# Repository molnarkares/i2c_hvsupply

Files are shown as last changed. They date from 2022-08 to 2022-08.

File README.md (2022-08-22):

# I2C controlled High voltage power supply for GM tubes

The device implements an I2C controlled variable output power supply (400V-600V), 
a GM tube pulse counter and an optional wake-up timer to trigger the host processor periodically.

The device was designed to keep the power consumption as low as possible. 

## Hardware

The physical hardware is a non-isolated flyback controller with 
voltage multiplier. The output voltage can be controlled by injecting bias current in the feedback loop of the controller IC. The circuit is using a PIC16LF1764 microcontroller.

## Firmware

The firmware is implemented in C using the Free License variant of the 
Microchip XC8 compiler 
See the readme in the firmware folder for details on operation and rebuild.

## Documentation

A comprehensive Users Manual is available in Latex format and converted to PDF in the doc folder.

## License

The project is available under MIT license, see the details in the sub-folders.

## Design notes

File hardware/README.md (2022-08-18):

# I2C controlled High voltage power supply for GM tubes

The device implements an I2C controlled variable output power supply (400V-600V), 
a GM tube pulse counter and an optional wake-up timer to trigger the host processor periodically.

The device was designed to keep the power consumption as low as possible. 

See the detailed Users Manual in the doc folder one level up. 

# PCB and Schematic Design

The circuit schematic and PCB was designed by [DesignSpark PCB v10](https://www.rs-online.com/designspark/pcb-software).

# License

## Hardware was designed by the Author

The complete desiggn is available under MIT license.

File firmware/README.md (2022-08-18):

# I2C controlled High voltage power supply for GM tubes

The device implements an I2C controlled variable output power supply (400V-600V), 
a GM tube pulse counter and an optional wake-up timer to trigger the host processor periodically.

The device was designed to keep the power consumption as low as possible. 

See the detailed Users Manual in the doc folder one level up. 

# Building the application

The BL can be built with the free version of the Microchip XC8 compiler. 
The related Makefile is exported from the MPLAB IDE. 
The software can be compiled with executing the _make_ command.

There are two build targets: 
* the _default_ target will link the application from the start address 0, 
so it can be uploaded by a debugger.
* the _reloc_ target will link to 0x400 and it is meant for uploading via the 
[I2C Boot loader](https://github.com/molnarkares/pic16f_i2cbl).

Observe that the software was developed on Linux host. a number of path settings
in the Makefile might require adjustment to rebuild it on other host OSes.

# License

## Code written by the Author

The complete business logic is written by the Author and it is available under MIT license.

## Generated code

The low level device drivers are generated by the Microchip MPLAB Code Configurator.
The generated code has its own copyright in the header of the concerned files.
These include the following files:
_tmr1-2-3-5.c/h_, _pin_manager.c/h_, _memory.c/h_, _mcc.c/h_, _i2c.c/h_, clc1-2.c/h and _interrupt_manager.h_

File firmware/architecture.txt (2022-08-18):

@startuml
package "Pulse counter" as pulsecounter {
    component TMR3_16 #Green
    component TMR2_8 #Green
    component CLC2 #Yellow

    TMR3_16 -> CLC2
    CLC2 -> TMR2_8
}
package "Periodic notification timer" as sectimer {
    component TMR1_16 #Green
    component TMR5_16 #Green
    component CLC1 #Yellow
    
    TMR1_16 -> CLC1
    CLC1 -> PA2
    PA2 -> TMR5_16

}
package pwm {
    component PWM5 #Green
}
package "Command processor" as cmd {
    
    database registermap
    node commander
    component i2c #Green    
}
package System {
    component LFINTOSC #Green
}

interface "PWM output" as RC4
interface "TRIG" as RC2
interface "Pulse IN" as RC5 
interface "Secondary OSC" as RA4_5

interface "SCL" as RA1
interface "SDA" as RA0

TMR1_16 <-- RA4_5
TMR3_16 <-- RC5

RA1 <-up-> i2c
RA0 <-up-> i2c

PWM5 -down-> RC4
registermap <-> commander
i2c <-left-> commander
commander -down-> RC2
commander -> pwm

note bottom of TMR5_16
wakes up MCU after a given number of seconds
end note 
note bottom of i2c
wakes up MCU at address match
end note 

LFINTOSC -> commander
LFINTOSC -> PWM5
LFINTOSC -> i2c
@enduml

@startuml
start
if (Connection to Ginkgo sucessful?) then (yes)
#Cyan: Verify primary I2C connection
    by reading the default I2C values;
    if (Values matching default) then(yes)
#Cyan: Test pulse counter;
        if (pulse readback matches) then(yes)
        #Cyan: Test timeout and TRIG pin;
            if (Timout within 1ms jitter?) then (yes)
            #Cyan: Calibrate ADC;
            #Cyan: Write back VADJUST values;
            #Cyan: Write serial number;
            #Cyan: Write default values
            Vout disabled
            No timeout;
            else (no)
            #Crimson:report Error;
            stop
        endif
        else(no)
#Crimson:report Error;
        stop
        endif
    else(no)
#Crimson: report Error;
    stop
    endif
else (no)
#Crimson:report Error;
  stop
endif
end

@enduml

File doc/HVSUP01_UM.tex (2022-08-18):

% This file was converted to LaTeX by Writer2LaTeX ver. 1.4
% see http://writer2latex.sourceforge.net for more info
\documentclass[a4paper]{article}
\usepackage[ascii]{inputenc}
\usepackage[T1]{fontenc}
\usepackage[english]{babel}
\usepackage{amsmath}
\usepackage{amssymb,amsfonts,textcomp}
\usepackage{color}
\usepackage{array}
\usepackage{supertabular}
\usepackage{hhline}
\usepackage{hyperref}
\hypersetup{pdftex, colorlinks=true, linkcolor=blue, citecolor=blue, filecolor=blue, urlcolor=blue, pdftitle=, pdfauthor=, pdfsubject=, pdfkeywords=}
\usepackage[pdftex]{graphicx}
% footnotes configuration
\makeatletter
\renewcommand\thefootnote{\arabic{footnote}}
\makeatother
% Outline numbering
\setcounter{secnumdepth}{0}
\makeatletter
\newcommand\arraybslash{\let\\\@arraycr}
\makeatother
% List styles
\newcommand\liststyleLi{%
\renewcommand\labelitemi{{\textbullet}}
\renewcommand\labelitemii{${\circ}$}
\renewcommand\labelitemiii{${\blacksquare}$}
\renewcommand\labelitemiv{{\textbullet}}
}
\newcommand\liststyleLii{%
\renewcommand\theenumi{\arabic{enumi}}
\renewcommand\theenumii{\arabic{enumii}}
\renewcommand\theenumiii{\arabic{enumiii}}
\renewcommand\theenumiv{\arabic{enumiv}}
\renewcommand\labelenumi{\theenumi.}
\renewcommand\labelenumii{\theenumii.}
\renewcommand\labelenumiii{\theenumiii.}
\renewcommand\labelenumiv{\theenumiv.}
}
% Page layout (geometry)
\setlength\voffset{-1in}
\setlength\hoffset{-1in}
\setlength\topmargin{0.7874in}
\setlength\oddsidemargin{0.7874in}
\setlength\textheight{9.235in}
\setlength\textwidth{6.695299in}
\setlength\footskip{0.4402in}
\setlength\headheight{0.2402in}
\setlength\headsep{0.2in}
% Footnote rule
\setlength{\skip\footins}{1.18034mm}
\renewcommand\footnoterule{\vspace*{-0.0071in}\setlength\leftskip{0pt}\setlength\rightskip{0pt plus 1fil}\noindent\textcolor{black}{\rule{0.25\columnwidth}{0.0071in}}\vspace*{1mm}}
% Pages styles
\makeatletter
\newcommand\ps@Standard{
  \renewcommand\@oddhead{}
  \renewcommand\@evenhead{\@oddhead}
  \renewcommand\@oddfoot{August 2022 \hfill {\textcopyright} Karoly Molnar \hfill Specification subject to change without notice. }
  \renewcommand\@evenfoot{\@oddfoot}
  \renewcommand\thepage{\arabic{page}}
}
\makeatother
\pagestyle{Standard}
\setlength\tabcolsep{1mm}
\renewcommand\arraystretch{1.3}
\newcounter{Drawing}
\renewcommand\theDrawing{\arabic{Drawing}}
\title{}
\author{}
\date{2020-10-24}
\begin{document}

\bigskip

{\centering\selectlanguage{english}\sffamily\bfseries
HVSUP01
\par}

{\centering\selectlanguage{english}\sffamily
Composite I2C sensor 
\par}

{\centering\selectlanguage{english}\sffamily
for 
\par}

{\centering\selectlanguage{english}\sffamily
radiation detector (GM) tubes
\par}

\bigskip

\bigskip

\bigskip

{\centering\selectlanguage{english}\sffamily
User Manual
\par}

\setcounter{tocdepth}{10}
\renewcommand\contentsname{Table of Contents}
\tableofcontents
\section[]{\selectlanguage{english} }
\clearpage\section[Introduction]{\selectlanguage{english} Introduction}
\hypertarget{RefHeadingToc1311383566216}{}{\selectlanguage{english}
The HVSUP01 sensor provides simple and flexible interface between a host processor and a radiation detector tube. The
device requires minimal external components and its properties can be configured via I2C interface. The low current
consumption of the sensor makes it ideal for building ultra low power radiation detector devices.}

\section[HIGH VOLTAGE WARNING]{\selectlanguage{english} HIGH VOLTAGE WARNING}
\hypertarget{RefHeadingToc3481383566216}{}\begin{center}
\tablefirsthead{}
\tablehead{}
\tabletail{}
\tablelasttail{}
\begin{supertabular}{|m{6.6163597in}|}
\hline
{\selectlanguage{english}\color[rgb]{0.8,0.0,0.0} The sensor is producing high voltage during normal operation. }

{\selectlanguage{english}\color[rgb]{0.8,0.0,0.0} Its pins, including any electrically conductive device that is
connected to its terminals, must not be touched while the device is operational. }

{\selectlanguage{english}\color[rgb]{0.8,0.0,0.0} The high voltage terminals shall be shorted after powering off the
device, to make sure that no high voltage charge remains in the sensor.}\\\hline
\end{supertabular}
\end{center}
\section[]{\selectlanguage{english} }
\section[Features]{\selectlanguage{english} Features}
\hypertarget{RefHeadingToc2781383566216}{}\liststyleLi
\begin{itemize}
\item {\selectlanguage{english}
3V input}
\item {\selectlanguage{english}
400-600V output voltage, digitally adjustable}
\item {\selectlanguage{english}
low input current typ. {\textless}60uA at 400V output and no load}
\item {\selectlanguage{english}
24 bits pulse counter}
\item {\selectlanguage{english}
Timer with crystal oscillator to trigger Wake{}-up output}
\item {\selectlanguage{english}
Built-in output current limiting resistor 4.5MOhm}
\item {\selectlanguage{english}
I2C slave interface max 400kHz}
\item {\selectlanguage{english}
I2C address is 0x6E (7bits)}
\end{itemize}
\section[]{\selectlanguage{english} }
\clearpage\section[Technical specifications]{\selectlanguage{english} Technical specifications}
\hypertarget{RefHeadingToc1331383566216}{}\subsection[Electrical parameters]{\selectlanguage{english} Electrical
parameters}
\hypertarget{RefHeadingToc2801383566216}{}\begin{center}
\tablefirsthead{}
\tablehead{}
\tabletail{}
\tablelasttail{}
\begin{supertabular}{|m{4.21016in}|m{2.32756in}|}
\hline
{\selectlanguage{english}\bfseries Absolute ratings} &
{\selectlanguage{english}\bfseries Value}\\\hline
{\selectlanguage{english} Supply voltage Vcc} &
{\selectlanguage{english} 2.6V -- 3.5V}\\\hline
{\selectlanguage{english} Output Voltage} &
{\selectlanguage{english} 400V-600V digitally adjustable}\\\hline
{\selectlanguage{english} Output resistance} &
{\selectlanguage{english} 4.5MOhm}\\\hline
{\selectlanguage{english} Maximum voltage on digital I/O pins} &
{\selectlanguage{english} Supply voltage + 0.2V}\\\hline
\end{supertabular}
\end{center}

\bigskip

\begin{center}
\tablefirsthead{}
\tablehead{}
\tabletail{}
\tablelasttail{}
\begin{supertabular}{|m{4.21016in}|m{2.32756in}|}
\hline
\multicolumn{2}{|m{6.61646in}|}{{\selectlanguage{english}\bfseries Typical parameters @ 3V input voltage}}\\\hline
{\selectlanguage{english} Output Voltage accuracy @no load} &
{\selectlanguage{english} +/-3V}\\\hline
{\selectlanguage{english} Standby current consumption with output disabled} &
{\selectlanguage{english} 5uA}\\\hline
{\selectlanguage{english} Standby current consumption @400V no load} &
{\selectlanguage{english} 60uA}\\\hline
{\selectlanguage{english} Standby current consumption @500V no load} &
{\selectlanguage{english} 90uA}\\\hline
{\selectlanguage{english} Standby current consumption @600V no load} &
{\selectlanguage{english} 120uA}\\\hline
{\selectlanguage{english} Inrush current at starting the high voltage stage } &
{\selectlanguage{english} 300mA @ 40ms}\\\hline
\end{supertabular}
\end{center}
\clearpage\subsection[Timing parameters]{\selectlanguage{english} Timing parameters}
\hypertarget{RefHeadingToc7013613373551}{}\label{bkm:RefHeadingToc7013613373551}\begin{center}
\tablefirsthead{}
\tablehead{}
\tabletail{}
\tablelasttail{}
\begin{supertabular}{|m{4.20946in}|m{2.3281598in}|}
\hline
\multicolumn{2}{|m{6.6163597in}|}{{\selectlanguage{english}\bfseries Typical parameters at 3V input voltage}}\\\hline
{\selectlanguage{english} Pulse width of TRIG output} &
{\selectlanguage{english} approx. 1 msec}\\\hline
{\selectlanguage{english} Wake-up timeout accuracy} &
{\selectlanguage{english} +/- 30ppm}\\\hline
{\selectlanguage{english} I2C interface clock frequency} &
{\selectlanguage{english} max 400kHz}\\\hline
{\selectlanguage{english} Detected pulses per second} &
{\selectlanguage{english} 0...5000}\\\hline
{\selectlanguage{english} I2C clock stretching } &
{\selectlanguage{english} max 10ms}\\\hline
{\selectlanguage{english} Voltage ramp-up time} &
{\selectlanguage{english} approx. 50 sec}\\\hline
\end{supertabular}
\end{center}
\subsection[Environmental conditions]{\selectlanguage{english} Environmental conditions}
\hypertarget{RefHeadingToc2821383566216}{}\begin{center}
\tablefirsthead{}
\tablehead{}
\tabletail{}
\tablelasttail{}
\begin{supertabular}{|m{4.21016in}|m{2.32756in}|}
\hline
\multicolumn{2}{|m{6.61646in}|}{{\selectlanguage{english}\bfseries Absolute ratings}}\\\hline
{\selectlanguage{english} Operational temperature} &
{\selectlanguage{english} {}-20{\textdegree}C ... 50{\textdegree}C}\\\hline
{\selectlanguage{english} Storage temperature} &
{\selectlanguage{english} {}-20{\textdegree}C ... 70{\textdegree}C}\\\hline
{\selectlanguage{english} Relative Humidity} &
{\selectlanguage{english} 10\%..90\% non-condensing}\\\hline
\end{supertabular}
\end{center}
\clearpage\section[Operation]{\selectlanguage{english} Operation}
\hypertarget{RefHeadingToc1351383566216}{}\subsection[General behavior]{\selectlanguage{english} General behavior}
\hypertarget{RefHeadingToc2841383566216}{}{\selectlanguage{english}
The device is an I2C slave peripheral that can output high voltage. It is intended to count the detected pulses of a
connected GM tube. The sensor contains all signal shaping circuit that is necessary for accurate and error-free
detection of the pulses.}

\bigskip

\subsection[]{\selectlanguage{english} }
\begin{center}
\begin{minipage}{3.2874in}
{\selectlanguage{english}\itshape
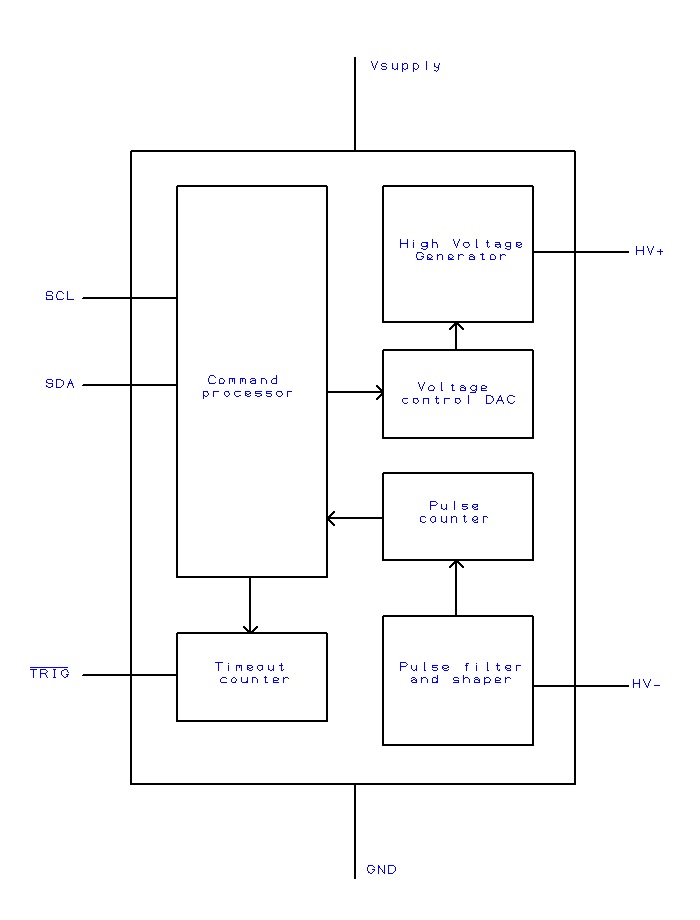
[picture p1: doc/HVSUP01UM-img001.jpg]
  \stepcounter{Drawing}{\theDrawing}. Drawing:
Block diagram}
\end{minipage}
\end{center}
\subsection[]{\selectlanguage{english} }
\clearpage\subsection[Configuration]{\selectlanguage{english} Configuration}
\hypertarget{RefHeadingToc3521383566216}{}{\selectlanguage{english}
The device has two configurable parameters: the output voltage and the timeout.}

\subsubsection[Output voltage]{\selectlanguage{english} Output voltage}
\hypertarget{RefHeadingToc3541383566216}{}{\selectlanguage{english}
The voltage is a 16bits parameter with valid range from 400V to 600V. The given value is the output of the high voltage
front-end. Setting the voltage out of the allowed range will turn off the high voltage generator, while the rest of the
device, e.g. timeout and pulse counter, remains functional. }

{\selectlanguage{english}
The default value of the parameter is zero, i.e. the high voltage generator is turned off. For proper functionality the
value shall be configured to the operational voltage of the connected GM tube.}

\subsubsection[Timeout]{\selectlanguage{english} Timeout}
\hypertarget{RefHeadingToc3561383566216}{}{\selectlanguage{english}
The timeout is a 16 bits parameter in seconds. Setting the parameter to a value different than zero will generate an
active low signal on the TRIG pin of the device. Parameter zero will turn off the TRIG signaling. }

{\selectlanguage{english}
The default value of the parameter is zero. }

\subsection[Reading pulse count]{\selectlanguage{english} Reading pulse count}
\hypertarget{RefHeadingToc7033613373551}{}{\selectlanguage{english}
The pulse count value is a 24bits number. It is incremented by every pulse from the attached GM tube. The number of
pulses for a given radiation level is characteristic for each GM tube.}

{\selectlanguage{english}
If the timeout is set to zero then the counter value reflects the number of pulses since the last readout. If the
timeout is non-zero then the value is reflecting the number of pulses in the previous complete timeout period, and
remains the same until a new timeout occurs.}

\subsection[]{\selectlanguage{english} }
\clearpage\subsection[Reading factory data]{\selectlanguage{english} Reading factory data}
\hypertarget{RefHeadingToc7053613373551}{}\subsubsection[Firmware version]{\selectlanguage{english} Firmware version}
\hypertarget{RefHeadingToc7073613373551}{}{\selectlanguage{english}
The value is a 16 bits number, with MSB denoting the major and LSB denoting the minor software version.}

\subsubsection[Hardware version]{\selectlanguage{english} Hardware version}
\hypertarget{RefHeadingToc7093613373551}{}{\selectlanguage{english}
The value is a 16 bits number, with MSB denoting the major and LSB denoting the minor hardware version. }

\subsubsection[Serial number]{\selectlanguage{english} Serial number}
\hypertarget{RefHeadingToc7113613373551}{}{\selectlanguage{english}
The value is a 32 bits number that is unique for each device.}

\subsection[Typical operation]{\selectlanguage{english} Typical operation}
\hypertarget{RefHeadingToc2861383566216}{}{\selectlanguage{english}
The sensor can be connected to a 3V compliant I2C bus directly. The digital pins of the device are not 5V tolerant!}

{\selectlanguage{english}
Proper pull-up resistors shall be connected to the SCL and SDA lines, typically 4.7KOhm is sufficient. The open-drain
TRIG pin can be optionally connected to the wake-up, interrupt or reset pin of the MCU. This may be beneficial if the
host MCU is put in deep sleep mode between measurements. The HVSUP01 device can ensure that the host MCU is woken up
periodically by pulling down the TRIG pin for about 1ms, after the timeout elapses.}

\bigskip

\subsection[]{\selectlanguage{english} }
\clearpage\section[Digital interface]{\selectlanguage{english} Digital interface}
\hypertarget{RefHeadingToc1371383566216}{}\subsection[I2C (SCL and SDA)]{\selectlanguage{english} I2C (SCL and SDA)}
\hypertarget{RefHeadingToc1300441299070}{}{\selectlanguage{english}
The device can be interfaced to an I2C master host that supports Standard and Fast Mode communication. The sensor has a
set of registers that can be read and written. The registers can be accessed either individually or in group. The I2C
bus specification is not detailed here. For further reference see [1]}

{\selectlanguage{english}
The device can be accessed at the I2C address 0x6E. The address cannot be modified. }

{\selectlanguage{english}
The I2C command processor of the sensor evaluates the register changes after each STOP condition. Therefore it is
recommended to write the configuration parameters in atomic 16bits steps or consecutive registers in one 32bits step.}

{\selectlanguage{english}
\textit{Application hint: Although modifying individual register bytes is possible, it may lead to undesired
functionality. For example, if the timeout value 0x00FF is changed to 0x0101 in two steps then writing an individual
0x01 to LSB while the MSB is still 0x00, would trigger a wake-up request at the next second instead of 257 seconds.}}

\subsubsection[Access of the device]{\selectlanguage{english} Access of the device}
\hypertarget{RefHeadingToc12271084818799}{}{\selectlanguage{english}
The registers of the device appear like an array of bytes. The desired register can be selected by a one byte address
value that is written to the device. This may be followed by a sequence of write or read requests.}

\subsubsection[Writing data to the device]{\selectlanguage{english} Writing data to the device}
\hypertarget{RefHeadingToc12291084818799}{}{\selectlanguage{english}
Several consecutive bytes can be written with a single write sequence, followed by a STOP. The picture below
demonstrates and example, where two bytes are written to the register address 0x03 (timeout register).}

\begin{center}
\begin{minipage}{6.9252in}
{\selectlanguage{english}\itshape
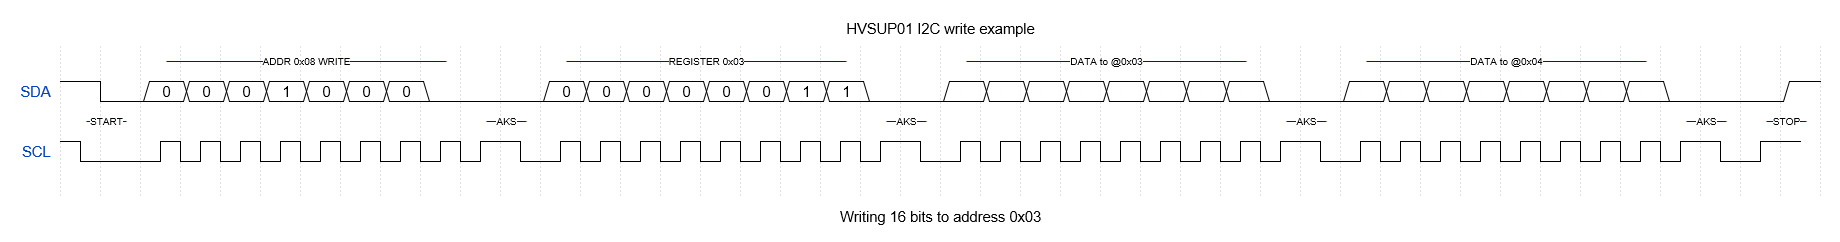
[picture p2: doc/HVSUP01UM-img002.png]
  \stepcounter{Drawing}{\theDrawing}. Drawing: I2C
write}
\end{minipage}
\end{center}
\subsubsection[Reading data from the device]{\selectlanguage{english} Reading data from the device}
\hypertarget{RefHeadingToc12311084818799}{}{\selectlanguage{english}
\ Several consecutive bytes can be read then with a single read sequence that is terminated by a NACK from the host,
followed by a STOP sequence. The picture below demonstrates and example, where two bytes are read from the register
address 0x03 (timeout register).}

\begin{center}
\begin{minipage}{6.9252in}
{\selectlanguage{english}\itshape
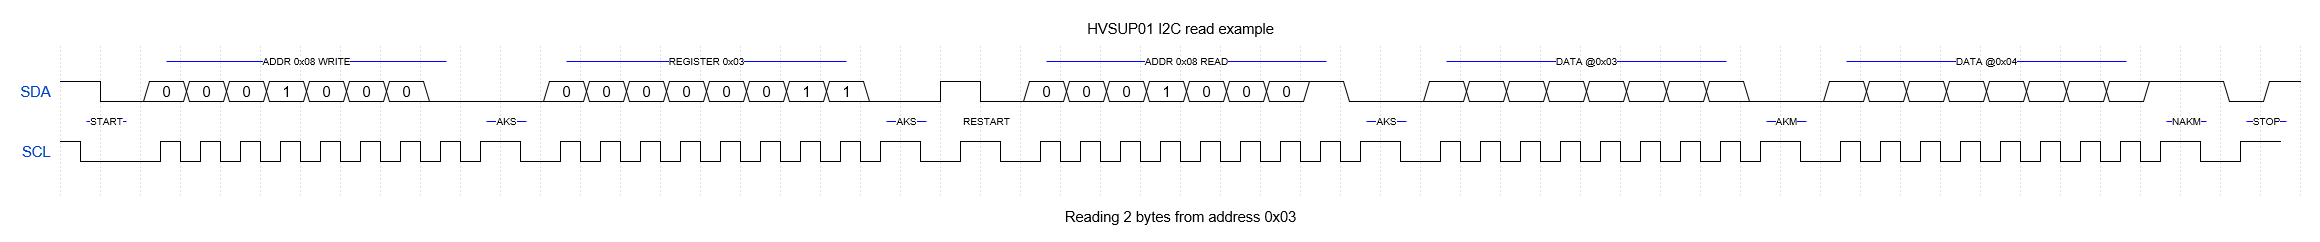
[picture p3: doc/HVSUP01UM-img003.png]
  \stepcounter{Drawing}{\theDrawing}. Drawing: I2C
read}
\end{minipage}
\end{center}
\subsubsection[Clock stretching]{\selectlanguage{english} Clock stretching}
\hypertarget{RefHeadingToc10431084818799}{}{\selectlanguage{english}
In order to maintain reliable communication in the specified I2C clock range, the device is using clock stretching. This
is completely transparent to the host application in most cases. If the host is using software emulation for I2C
communication, it might be necessary to set the clock stretch timeout explicitly. Observe the value specified in
chapter Timing parameters.}

\subsection[TRIG output]{\selectlanguage{english} TRIG output}
\hypertarget{RefHeadingToc1302441299070}{}{\selectlanguage{english}
The TRIG pin is a configurable open-drain output. The device is setting the pin to active LOW for 1 millisecond, with
the period that is defined by the timeout register value.}

\clearpage\section[Memory map]{\selectlanguage{english} Memory map}
\hypertarget{RefHeadingToc1391383566216}{}
\bigskip

\begin{flushleft}
\tablefirsthead{}
\tablehead{}
\tabletail{}
\tablelasttail{}
\begin{supertabular}{|m{0.7976598in}|m{1.9136599in}|m{1.3045598in}|m{1.1761599in}|}
\hline
{\selectlanguage{english}\bfseries Address} &
{\selectlanguage{english}\bfseries Register} &
{\selectlanguage{english}\bfseries Read/Write} &
{\selectlanguage{english}\bfseries Value after power-up}\\\hline
{\selectlanguage{english} 0x00} &
{\selectlanguage{english} PulseCount[7..0]} &
{\selectlanguage{english} Read only} &
{\selectlanguage{english} 0}\\\hline
{\selectlanguage{english} 0x01} &
{\selectlanguage{english} PulseCount[15..8]} &
{\selectlanguage{english} Read only} &
{\selectlanguage{english} 0}\\\hline
{\selectlanguage{english} 0x02} &
{\selectlanguage{english} PulseCount[23..16]} &
{\selectlanguage{english} Read only} &
{\selectlanguage{english} 0}\\\hline
{\selectlanguage{english} 0x03} &
{\selectlanguage{english} Timeout[7..0]} &
{\selectlanguage{english} Read - Write} &
{\selectlanguage{english} 0}\\\hline
{\selectlanguage{english} 0x04} &
{\selectlanguage{english} Timeout[15..8]} &
{\selectlanguage{english} Read - Write} &
{\selectlanguage{english} 0}\\\hline
{\selectlanguage{english} 0x05} &
{\selectlanguage{english} Voltage[7..0]} &
{\selectlanguage{english} Read - Write} &
{\selectlanguage{english} 0}\\\hline
{\selectlanguage{english} 0x06} &
{\selectlanguage{english} Voltage[15..8]} &
{\selectlanguage{english} Read - Write} &
{\selectlanguage{english} 0}\\\hline
{\selectlanguage{english} 0x07} &
{\selectlanguage{english} HW Version [7..0]} &
{\selectlanguage{english} Read only} &
{\selectlanguage{english} varies\footnotemark{}}\\\hline
{\selectlanguage{english} 0x08} &
{\selectlanguage{english} HW Version [15..8]} &
{\selectlanguage{english} Read only} &
{\selectlanguage{english} varies}\\\hline
{\selectlanguage{english} 0x09} &
{\selectlanguage{english} Firmware Version [7..0]} &
{\selectlanguage{english} Read only} &
{\selectlanguage{english} varies}\\\hline
{\selectlanguage{english} 0x0A} &
{\selectlanguage{english} Firmware Version [15..8]} &
{\selectlanguage{english} Read only} &
{\selectlanguage{english} varies}\\\hline
{\selectlanguage{english} 0x0B} &
{\selectlanguage{english} Serial Number[7..0]} &
{\selectlanguage{english} Read only} &
{\selectlanguage{english} varies}\\\hline
{\selectlanguage{english} 0x0C} &
{\selectlanguage{english} Serial Number[15..8]} &
{\selectlanguage{english} Read only} &
{\selectlanguage{english} varies}\\\hline
{\selectlanguage{english} 0x0D} &
{\selectlanguage{english} Serial Number[23..16]} &
{\selectlanguage{english} Read only} &
{\selectlanguage{english} varies}\\\hline
{\selectlanguage{english} 0x0E} &
{\selectlanguage{english} Serial Number[31..24]} &
{\selectlanguage{english} Read only} &
{\selectlanguage{english} varies}\\\hline
\end{supertabular}
\end{flushleft}
\footnotetext{The HW, Firmware and Serial number values designate a given device, hence there is no fix default value}

\bigskip

\subsection[Endianness]{\selectlanguage{english} Endianness}
\hypertarget{RefHeadingToc9151801770043}{}{\selectlanguage{english}
All register values are stored in little endian byte order.}

\clearpage\section[Connection setup]{Connection setup}
\hypertarget{RefHeadingToc13004280169782}{}A typical connection is demonstrated on picture \ref{seq:refDrawing3}\ below.

\subsubsection[]{}
\begin{center}
\begin{minipage}{6.9252in}
{\selectlanguage{english}\itshape
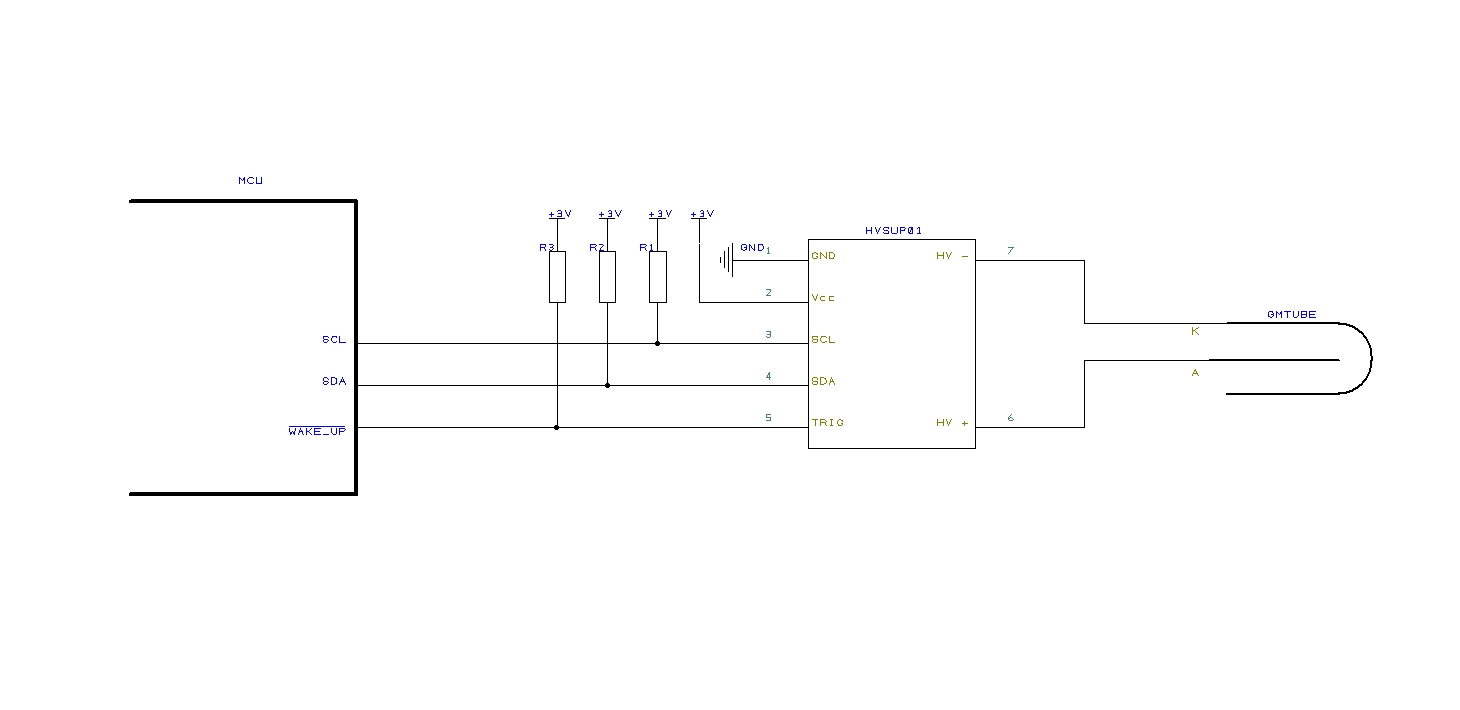
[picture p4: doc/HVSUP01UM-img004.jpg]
  \newline
{\refstepcounter{Drawing}\theDrawing\label{seq:refDrawing3}}. Drawing: Typical connection}
\end{minipage}
\end{center}
\subsubsection{Power supply}
\hypertarget{RefHeadingToc13044280169782}{}During normal operation the sensor is generating very short, high current
pulses on the power input. If the circuit is powered from a low power LDO rated less than 400mA, then it is suggested
to connect a relatively large capacitor (e.g. 0.3F supercap) between Vcc and GND and connect a series resistor in a few
Ohms range between the LDO and the capacitor. See picture \ref{seq:refDrawing4}\ below.

\begin{center}
\begin{minipage}{6.6953in}
{\itshape
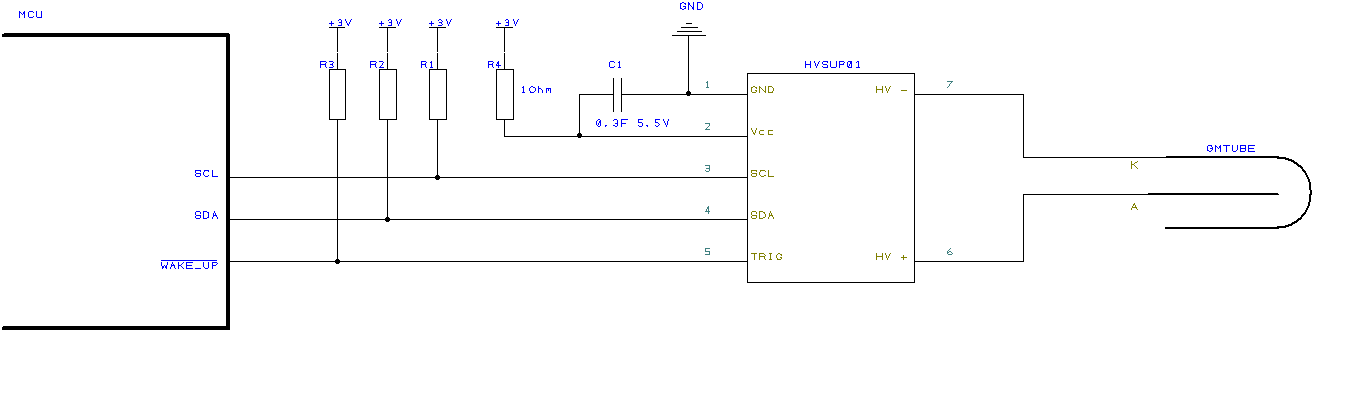
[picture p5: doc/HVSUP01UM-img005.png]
 
{\refstepcounter{Drawing}\theDrawing\label{seq:refDrawing4}}. Drawing: Typical connection with weak power supply}
\end{minipage}
\end{center}
\subsubsection[Detector noise]{\selectlanguage{english} Detector noise}
\hypertarget{RefHeadingToc4061383566216}{}The High Voltage front-end contains filtering and signal shaping features to
eliminate most electrical noise that could influence the measurement. Large noise signal on the terminals of the sensor
can still negatively affect the pulse count value. Therefore it is recommended to ensure that the connection between
the device and the detector tube is as short as possible. If the distance between the sensor and the tube is longer
than 15-30cm then shielded cable can be used with two inner conductors.

\clearpage\section[Package]{\selectlanguage{english} Package}
\hypertarget{RefHeadingToc1411383566216}{}{\selectlanguage{english}
The sensor is available in epoxy filled ABS package.}

\subsection[Pin configuration]{\selectlanguage{english} Pin configuration}
\hypertarget{RefHeadingToc1431383566216}{}{\selectlanguage{english}
Bottom view of the device with pin numbers:}

\begin{center}
\begin{minipage}{2.0272in}
{\selectlanguage{english}\itshape
[Warning: Draw object ignored]\stepcounter{Drawing}{\theDrawing}. Drawing: Pin numbering}
\end{minipage}
\end{center}
\begin{flushleft}
\tablefirsthead{}
\tablehead{}
\tabletail{}
\tablelasttail{}
\begin{supertabular}{|m{1.1712599in}|m{3.2962599in}|}
\hline
{\selectlanguage{english}\bfseries Pin number} &
{\selectlanguage{english}\bfseries Pin function}\\\hline
{\selectlanguage{english} 1} &
{\selectlanguage{english} GND}\\\hline
{\selectlanguage{english} 2} &
{\selectlanguage{english} Vcc}\\\hline
{\selectlanguage{english} 3} &
{\selectlanguage{english} SCL}\\\hline
{\selectlanguage{english} 4} &
{\selectlanguage{english} SDA}\\\hline
{\selectlanguage{english} 5} &
{\selectlanguage{english} TRIG}\\\hline
{\selectlanguage{english} 6} &
{\selectlanguage{english} HV +}\\\hline
{\selectlanguage{english} 7} &
{\selectlanguage{english} HV -}\\\hline
\end{supertabular}
\end{flushleft}
\subsection[]{\selectlanguage{english} }
\clearpage\subsection[Outline dimensions]{\selectlanguage{english} Outline dimensions}
\hypertarget{RefHeadingToc1451383566216}{}{\selectlanguage{english}
All dimensions are in millimeters.}

\begin{flushleft}
\tablefirsthead{}
\tablehead{}
\tabletail{}
\tablelasttail{}
\begin{supertabular}{|m{2.23236in}|m{2.0462599in}|}
\hline
{\selectlanguage{english} Length x width} &
{\selectlanguage{english} 36 mm x 36 mm}\\\hline
{\selectlanguage{english} Height without pins} &
{\selectlanguage{english} 15 mm}\\\hline
{\selectlanguage{english} Height with pins} &
{\selectlanguage{english} 21.5 mm}\\\hline
{\selectlanguage{english} Pin width} &
{\selectlanguage{english} 0.64 mm x 0.64 mm}\\\hline
\end{supertabular}
\end{flushleft}

\bigskip

\subsection[Pin placement dimensions]{\selectlanguage{english} Pin placement dimensions}
\hypertarget{RefHeadingToc12331084818799}{}
\bigskip

\begin{center}
\begin{minipage}{3.2563in}
{\selectlanguage{english}\itshape
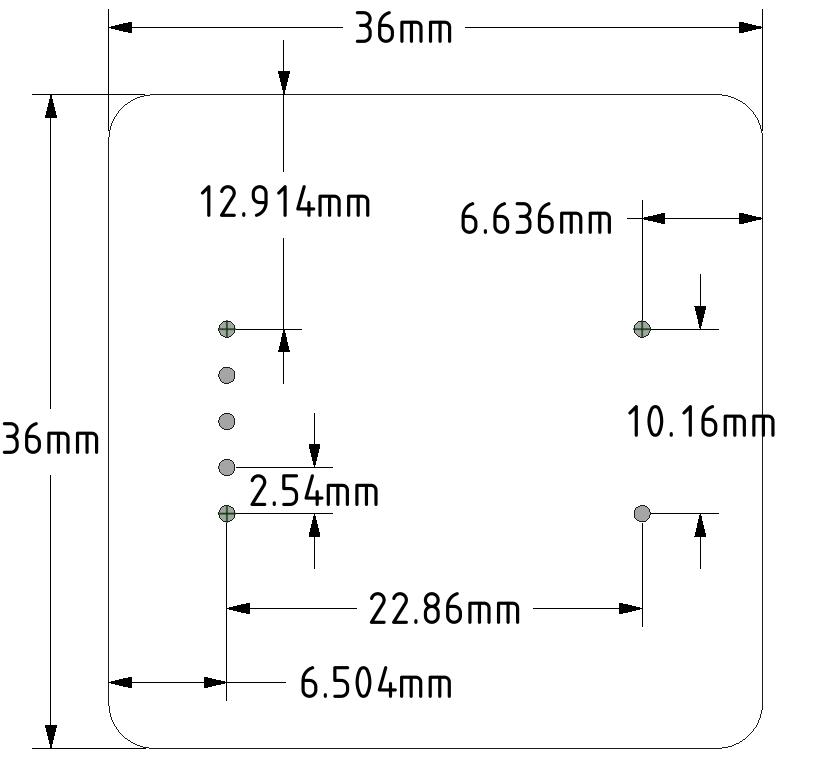
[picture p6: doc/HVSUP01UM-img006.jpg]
  \stepcounter{Drawing}{\theDrawing}. Drawing:
Mechanical drawing}
\end{minipage}
\end{center}
\clearpage
\bigskip

\subsection[Soldering and assembly recommendations]{\selectlanguage{english} Soldering and assembly recommendations}
\hypertarget{RefHeadingToc1471383566216}{}{\selectlanguage{english}
The HVSUP01 sensor is primarily suitable for manual soldering. The pins are gold plated which provides excellent
electrical connection when used with solder-less breadboards, too.}

{\selectlanguage{english}
The device is not suitable for any assembly process that could expose the encapsulation to temperatures higher than 80
{\textdegree}C or 176 {\textdegree}F.}

\clearpage\section[References]{\selectlanguage{english} References}
\hypertarget{RefHeadingToc9651801770043}{}\begin{flushleft}
\tablefirsthead{}
\tablehead{}
\tabletail{}
\tablelasttail{}
\begin{supertabular}{|m{0.7330598in}|m{6.03236in}|}
\hline
\liststyleLii
\begin{enumerate}
\item ~

\end{enumerate}
 &
{\selectlanguage{english} \href{https://www.nxp.com/docs/en/user-guide/UM10204.pdf}{\foreignlanguage{english}{I2C-bus
specification and user manual}}}\\\hline
~
 &
~
\\\hline
~
 &
~
\\\hline
\end{supertabular}
\end{flushleft}
\section[]{\selectlanguage{english} }
\clearpage\section[Legal disclaimer]{\selectlanguage{english} Legal disclaimer}
\hypertarget{RefHeadingToc1811383566216}{}{\selectlanguage{english}
The HVSUP01 sensor is intended for educational purpose only. }

{\selectlanguage{english}
The sensor may not fit for use in environment and purpose where the malfunction of the device could lead to bodily harm
or property damage. }

{\selectlanguage{english}
The user of the device understands and agrees that the prototyping sensor has not been fully certified, therefore its output data
must not be used for quantitative judgment of potentially high radiation. }

{\selectlanguage{english}
It is the user's responsibility to determine whether the product fits for the intended use in the prototyping
environment.}

{\selectlanguage{english}
The author of this project shall not be liable to any damages related to use of the device.}

{\selectlanguage{english}
{The sensor is not a Finished Appliance. In case the equipment is used as part of a Finished Appliance then the user of the device must take
responsibility for galvanic insulation from the environment and to follow regulatory guidelines, for example CE marking.}

\subsection[RoHS compliance]{\selectlanguage{english} RoHS compliance}
\hypertarget{RefHeadingToc3581383566216}{}{\selectlanguage{english}
Although the device has been built from RoHS compliant parts with RoHS compliant assembly process, no formal statement
is given here about RoHS compliance.}
\end{document}

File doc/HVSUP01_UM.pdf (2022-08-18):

HVSUP01
Composite I2C sensor
for
radiation detector (GM) tubes

User Manual

## Table of Contents

1

Introduction | 2
HIGH VOLTAGE WARNING | 2
| 2
Features | 2
| 2
Technical specications | 3
Operation | 5
Digital interface | 8
Memory map | 9
August 2022 | © Karoly Molnar | Specication subject to change without notice.

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

## Introduction

The HVSUP01 sensor provides simple and exible interface between a host processor and a radiation detector tube. The device requires minimal external components and its properties can be congured via I2C interface. The low current consumption of the sensor makes it ideal for building ultra low power radiation detector devices.

## HIGH VOLTAGE WARNING

The sensor is producing high voltage during normal operation.
Its pins, including any electrically conductive device that is connected to its terminals, must not be touched while the device is operational.
The high voltage terminals shall be shorted after powering o the device, to make sure that no high voltage charge remains in the sensor.

## Features

3V input

400-600V output voltage, digitally adjustable

low input current typ. <60uA at 400V output and no load

24 bits pulse counter

Timer with crystal oscillator to trigger Wake-up output

Built-in output current limiting resistor 4.5MOhm

I2C slave interface max 400kHz

I2C address is 0x6E (7bits)

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

## Operation

General behavior

The device is an I2C slave peripheral that can output high voltage. It is intended to count the detected pulses of a connected GM tube. The sensor contains all signal shaping circuit that is necessary for accurate and error-free detection of the pulses.


1. Drawing: Block diagram

Conguration

The device has two congurable parameters: the output voltage and the timeout.

Output voltage

The voltage is a 16bits parameter with valid range from 400V to 600V. The given value is the output of the high voltage front-end. Setting the voltage out of the allowed range will turn o the high voltage generator, while the rest of the device, e.g. timeout and pulse counter, remains functional.
The default value of the parameter is zero, i.e. the high voltage generator is turned o. For proper functionality the value shall be congured to the operational voltage of the connected GM tube.

Timeout

The timeout is a 16 bits parameter in seconds. Setting the parameter to a value dierent than zero will generate an active low signal on the TRIG pin of the device. Parameter zero will turn o the TRIG signaling.
The default value of the parameter is zero.

Reading pulse count

The pulse count value is a 24bits number. It is incremented by every pulse from the attached GM tube. The number of pulses for a given radiation level is characteristic for each GM tube.
If the timeout is set to zero then the counter value reects the number of pulses since the last readout. If the timeout is non-zero then the value is reecting the number of pulses in the previous complete timeout period, and remains the same until a new timeout occurs.

Reading factory data

Firmware version

The value is a 16 bits number, with MSB denoting the major and LSB denoting the minor software version.

Hardware version

The value is a 16 bits number, with MSB denoting the major and LSB denoting the minor hardware version.

Serial number

The value is a 32 bits number that is unique for each device.

Typical operation

The sensor can be connected to a 3V compliant I2C bus directly. The digital pins of the device are not 5V tolerant!
Proper pull-up resistors shall be connected to the SCL and SDA lines, typically 4.7KOhm is sucient. The open-drain TRIG pin can be optionally connected to the wake-up, interrupt or reset pin of the MCU. This may be benecial if the host MCU is put in deep sleep mode between measurements. The HVSUP01 device can ensure that the host MCU is woken up periodically by pulling down the TRIG pin for about 1ms, after the timeout elapses.

## Digital interface

I2C (SCL and SDA)

The device can be interfaced to an I2C master host that supports Standard and Fast Mode communication. The sensor has a set of registers that can be read and written. The registers can be accessed either individually or in group. The I2C bus specication is not detailed here. For further reference see [1]
The device can be accessed at the I2C address 0x6E. The address cannot be modied.
The I2C command processor of the sensor evaluates the register changes after each STOP condition. Therefore it is recommended to write the conguration parameters in atomic 16bits steps or consecutive registers in one 32bits step.
Application hint: Although modifying individual register bytes is possible, it may lead to undesired functionality. For example, if the timeout value 0x00FF is changed to 0x0101 in two steps then writing an individual 0x01 to LSB while the MSB is still 0x00, would trigger a wake-up request at the next second instead of 257 seconds.

Access of the device

The registers of the device appear like an array of bytes. The desired register can be selected by a one byte address value that is written to the device. This may be followed by a sequence of write or read requests.

Writing data to the device

Several consecutive bytes can be written with a single write sequence, followed by a STOP. The picture below demonstrates and example, where two bytes are written to the register address 0x03 (timeout register).

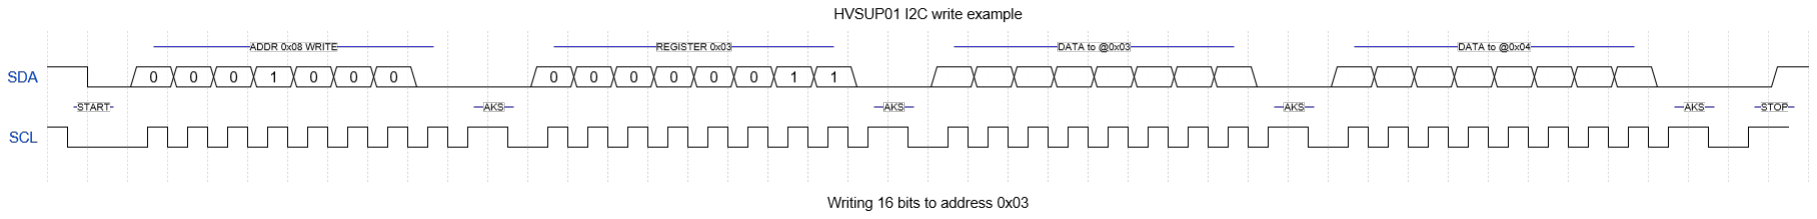
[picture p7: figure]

2. Drawing: I2C write

Reading data from the device

Several consecutive bytes can be read then with a single read sequence that is terminated by a NACK from the host, followed by a STOP sequence. The picture below demonstrates and example, where two bytes are read from the register address 0x03 (timeout register).

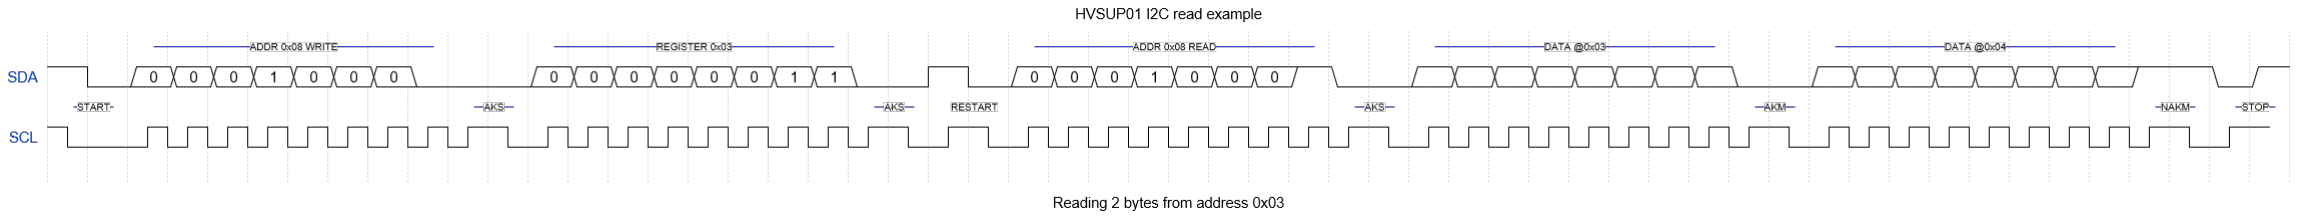
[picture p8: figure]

3. Drawing: I2C read

Clock stretching

In order to maintain reliable communication in the specied I2C clock range, the device is using clock stretching. This is completely transparent to the host application in most cases. If the host is using software emulation for I2C communication, it might be necessary to set the clock stretch timeout explicitly. Observe the value specied in chapter Timing parameters.

TRIG output

The TRIG pin is a congurable open-drain output. The device is setting the pin to active LOW for 1 millisecond, with the period that is dened by the timeout register value.

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

## Connection setup

A typical connection is demonstrated on picture 4 below.

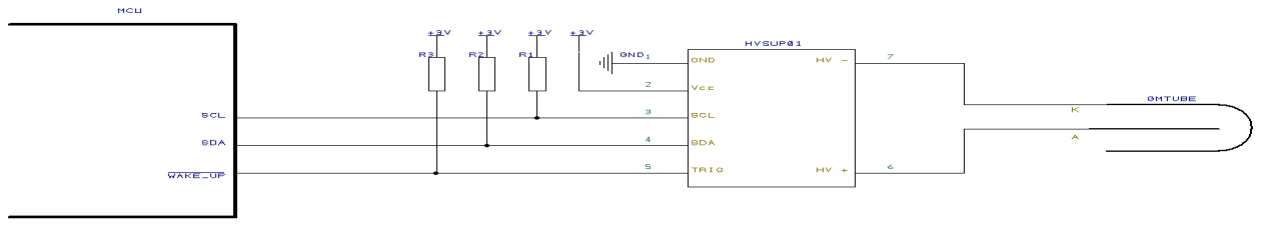
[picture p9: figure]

4. Drawing: Typical connection

Power supply

During normal operation the sensor is generating very short, high current pulses on the power input. If the circuit is powered from a low power LDO rated less than 400mA, then it is suggested to connect a relatively large capacitor (e.g. 0.3F supercap) between Vcc and GND and connect a series resistor in a few Ohms range between the LDO and the capacitor. See picture 5 below.

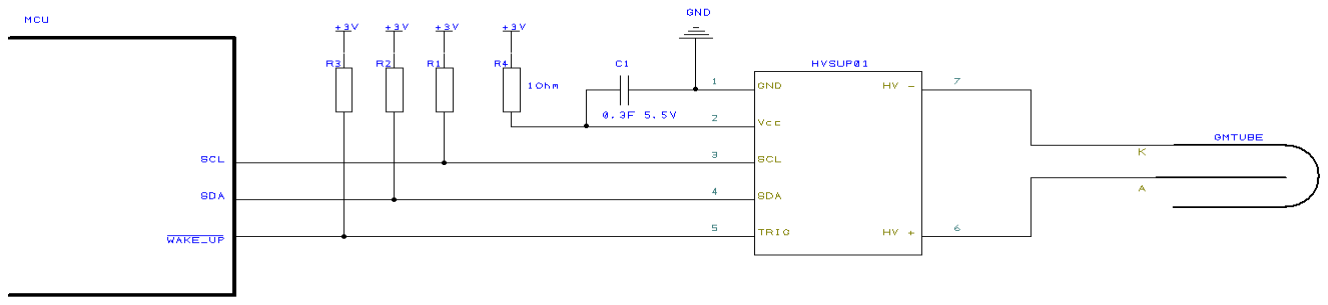
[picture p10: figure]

5. Drawing: Typical connection with weak power supply

Detector noise

The High Voltage front-end contains ltering and signal shaping features to eliminate most electrical noise that could inuence the measurement. Large noise signal on the terminals of the sensor can still negatively aect the pulse count value. Therefore it is recommended to ensure that the connection between the device and the detector tube is as short as possible. If the distance between the sensor and the tube is longer than 15-30cm then shielded cable can be used with two inner conductors.

## Package

The sensor is available in epoxy lled ABS package.

Pin conguration

Bottom view of the device with pin numbers:

[Warning: Draw object ignored]6. Drawing: Pin numbering

Pin number | Pin function
1 | GND
2 | Vcc
3 | SCL
4 | SDA
5 | TRIG
6 | HV +
7 | HV -

Outline dimensions

All dimensions are in millimeters.

Length x width | 36 mm x 36 mm
Height without pins | 15 mm
Height with pins | 21.5 mm
Pin width | 0.64 mm x 0.64 mm

Pin placement dimensions


7. Drawing: Mechanical drawing

Soldering and assembly recommendations

The HVSUP01 sensor is primarily suitable for manual soldering. The pins are gold plated which provides excellent electrical connection when used with solder-less breadboards, too.
The device is not suitable for any assembly process that could expose the encapsulation to temperatures higher than 80 °C or 176 °F.

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

## Legal disclaimer

The HVSUP01 sensor is intended for educational purpose only.
The sensor may not t for use in environment and purpose where the malfunction of the device could lead to bodily harm or property damage.
The user of the device understands and agrees that the prototyping sensor has not been fully certied, therefore its output data must not be used for quantitative judgment of potentially high radiation.
It is the user's responsibility to determine whether the product ts for the intended use in the prototyping environment.
The author of this project shall not be liable to any damages related to use of the device.
The sensor is not a Finished Appliance. In case the equipment is used as part of a Finished Appliance then the user of the device must take responsibility for galvanic insulation from the environment and to follow regulatory guidelines, for example CE marking.

RoHS compliance

Although the device has been built from RoHS compliant parts with RoHS compliant assembly process, no formal statement is given here about RoHS compliance.
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

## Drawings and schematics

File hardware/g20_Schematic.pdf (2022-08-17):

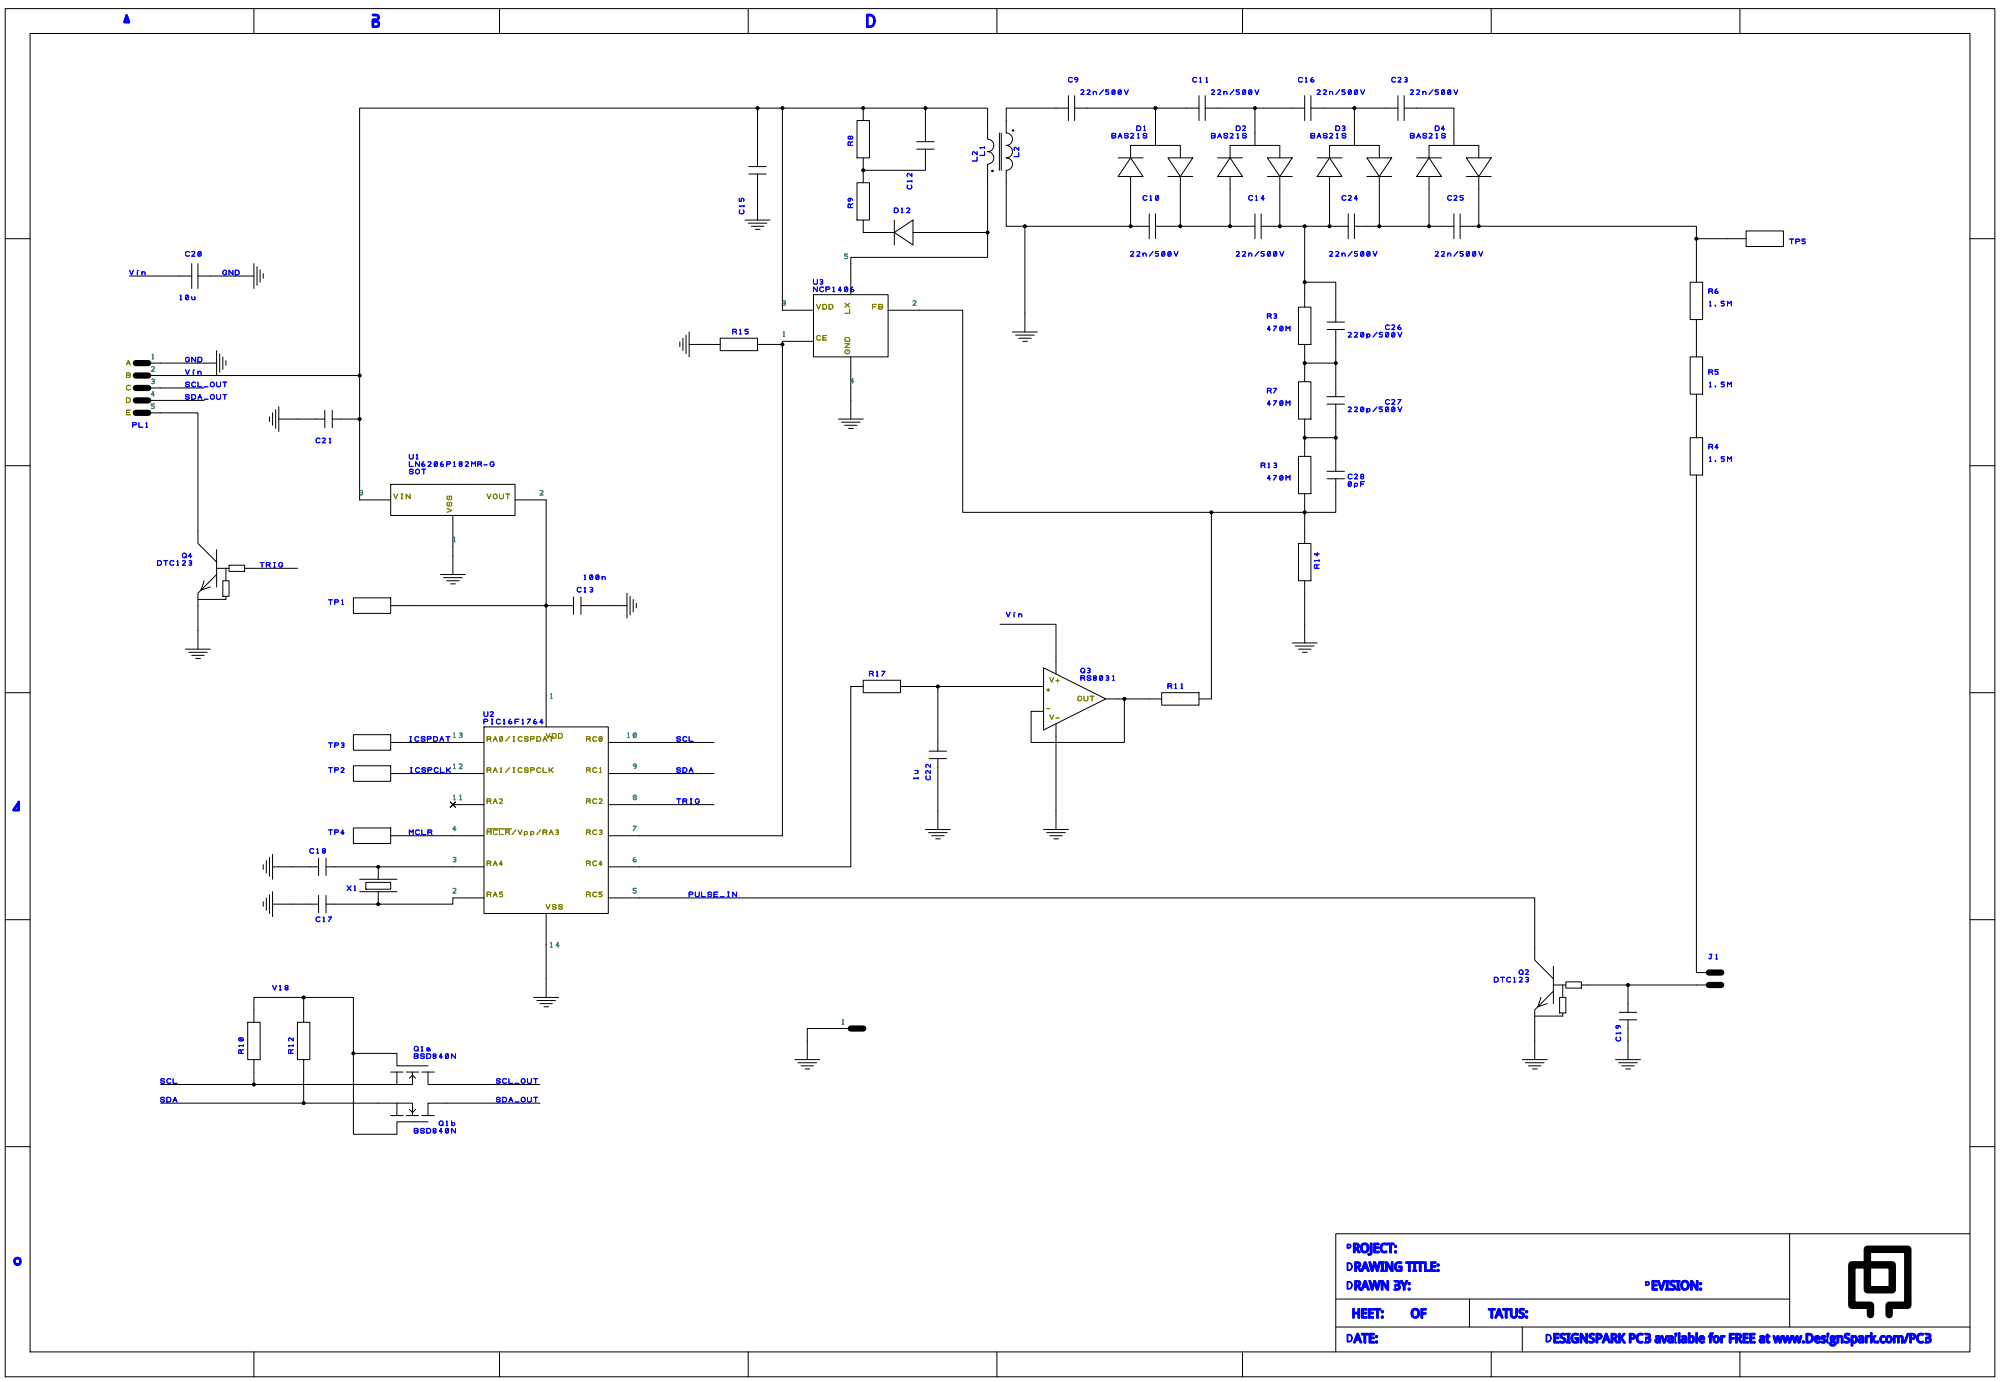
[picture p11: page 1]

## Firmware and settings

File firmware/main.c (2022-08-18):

/*
* Copyright (c) 2021-2022 Karoly Molnar <molnarkares@gmail.com>
*
* MIT license. See LICENSE for details.
 */

#include <xc.h>
#include "mcc.h"
#include "tmr1.h"
#include "tmr5.h"
#include "i2c.h"
#include "cmd.h"
#include "mrtc.h"
#include "vadjust.h"
#include "hven.h"
#include "pulsecount.h"
#include "config.h"
#include "sleep.h"
#include <stdint.h>



/*
                         Main application
 */
void main(void)
{
    INTERRUPT_GlobalInterruptDisable();
    SYSTEM_Initialize();
    TRIG_SetPushPull();
    RC0_ResetPullup();
    RC1_ResetPullup();
    TRIG_SetLow(); //after powerup it is the default
    voutInit();
    pwmDuty(PWM_MAX);
    RTCInit();
    cmdInit();
    (void)getPulseCount();

    INTERRUPT_PeripheralInterruptEnable();
    // Observe Global Interrupt is NOT enabled.

    while (1)
    {

        if(PIR1bits.SSP1IF == 1)
        {
            I2C_ISR();
        }
        else if((PIE4bits.TMR5IE == 1)&& (PIR4bits.TMR5IF == 1))
        {
            TMR5_ISR();
        }
        else if( (PIE1bits.TMR1IE == 1) && (PIR1bits.TMR1IF == 1))
        {
            TMR1_ISR();
        }
        rampUp();
#ifdef SAVEPARAMS          
        if(writeRequested) {
            writeRequested = saveNvParams(&nvparam);
        }else 
#endif        
        {
            gotoSleep();
        }
    }
}

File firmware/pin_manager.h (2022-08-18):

/**
    Copyright (c) 2013 - 2015 released Microchip Technology Inc.  All rights reserved.

    Microchip licenses to you the right to use, modify, copy and distribute
    Software only when embedded on a Microchip microcontroller or digital signal
    controller that is integrated into your product or third party product
    (pursuant to the sublicense terms in the accompanying license agreement).

    You should refer to the license agreement accompanying this Software for
    additional information regarding your rights and obligations.

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
*/


#ifndef PIN_MANAGER_H
#define PIN_MANAGER_H

#define INPUT   1
#define OUTPUT  0

#define HIGH    1
#define LOW     0

#define ANALOG      1
#define DIGITAL     0

#define PULL_UP_ENABLED      1
#define PULL_UP_DISABLED     0

// get/set T aliases
#define T_TRIS               TRISAbits.TRISA2
#define T_LAT                LATAbits.LATA2
#define T_PORT               PORTAbits.RA2
#define T_WPU                WPUAbits.WPUA2
#define T_OD                ODCONAbits.ODA2
#define T_ANS                ANSELAbits.ANSA2
#define T_SetHigh()            do { LATAbits.LATA2 = 1; } while(0)
#define T_SetLow()             do { LATAbits.LATA2 = 0; } while(0)
#define T_Toggle()             do { LATAbits.LATA2 = ~LATAbits.LATA2; } while(0)
#define T_GetValue()           PORTAbits.RA2
#define T_SetDigitalInput()    do { TRISAbits.TRISA2 = 1; } while(0)
#define T_SetDigitalOutput()   do { TRISAbits.TRISA2 = 0; } while(0)
#define T_SetPullup()      do { WPUAbits.WPUA2 = 1; } while(0)
#define T_ResetPullup()    do { WPUAbits.WPUA2 = 0; } while(0)
#define T_SetPushPull()    do { ODCONAbits.ODA2 = 1; } while(0)
#define T_SetOpenDrain()   do { ODCONAbits.ODA2 = 0; } while(0)
#define T_SetAnalogMode()  do { ANSELAbits.ANSA2 = 1; } while(0)
#define T_SetDigitalMode() do { ANSELAbits.ANSA2 = 0; } while(0)

// get/set RC0 procedures
#define RC0_SetHigh()    do { LATCbits.LATC0 = 1; } while(0)
#define RC0_SetLow()   do { LATCbits.LATC0 = 0; } while(0)
#define RC0_Toggle()   do { LATCbits.LATC0 = ~LATCbits.LATC0; } while(0)
#define RC0_GetValue()         PORTCbits.RC0
#define RC0_SetDigitalInput()   do { TRISCbits.TRISC0 = 1; } while(0)
#define RC0_SetDigitalOutput()  do { TRISCbits.TRISC0 = 0; } while(0)
#define RC0_SetPullup()     do { WPUCbits.WPUC0 = 1; } while(0)
#define RC0_ResetPullup()   do { WPUCbits.WPUC0 = 0; } while(0)
#define RC0_SetAnalogMode() do { ANSELCbits.ANSC0 = 1; } while(0)
#define RC0_SetDigitalMode()do { ANSELCbits.ANSC0 = 0; } while(0)

// get/set RC1 procedures
#define RC1_SetHigh()    do { LATCbits.LATC1 = 1; } while(0)
#define RC1_SetLow()   do { LATCbits.LATC1 = 0; } while(0)
#define RC1_Toggle()   do { LATCbits.LATC1 = ~LATCbits.LATC1; } while(0)
#define RC1_GetValue()         PORTCbits.RC1
#define RC1_SetDigitalInput()   do { TRISCbits.TRISC1 = 1; } while(0)
#define RC1_SetDigitalOutput()  do { TRISCbits.TRISC1 = 0; } while(0)
#define RC1_SetPullup()     do { WPUCbits.WPUC1 = 1; } while(0)
#define RC1_ResetPullup()   do { WPUCbits.WPUC1 = 0; } while(0)
#define RC1_SetAnalogMode() do { ANSELCbits.ANSC1 = 1; } while(0)
#define RC1_SetDigitalMode()do { ANSELCbits.ANSC1 = 0; } while(0)

// get/set TRIG aliases
#define TRIG_TRIS               TRISCbits.TRISC2
#define TRIG_LAT                LATCbits.LATC2
#define TRIG_PORT               PORTCbits.RC2
#define TRIG_WPU                WPUCbits.WPUC2
#define TRIG_OD                ODCONCbits.ODC2
#define TRIG_ANS                ANSELCbits.ANSC2
#define TRIG_SetHigh()            do { LATCbits.LATC2 = 1; } while(0)
#define TRIG_SetLow()             do { LATCbits.LATC2 = 0; } while(0)
#define TRIG_Toggle()             do { LATCbits.LATC2 = ~LATCbits.LATC2; } while(0)
#define TRIG_GetValue()           PORTCbits.RC2
#define TRIG_SetDigitalInput()    do { TRISCbits.TRISC2 = 1; } while(0)
#define TRIG_SetDigitalOutput()   do { TRISCbits.TRISC2 = 0; } while(0)
#define TRIG_SetPullup()      do { WPUCbits.WPUC2 = 1; } while(0)
#define TRIG_ResetPullup()    do { WPUCbits.WPUC2 = 0; } while(0)
#define TRIG_SetPushPull()    do { ODCONCbits.ODC2 = 0; } while(0)
#define TRIG_SetOpenDrain()   do { ODCONCbits.ODC2 = 1; } while(0)
#define TRIG_SetAnalogMode()  do { ANSELCbits.ANSC2 = 1; } while(0)
#define TRIG_SetDigitalMode() do { ANSELCbits.ANSC2 = 0; } while(0)
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
